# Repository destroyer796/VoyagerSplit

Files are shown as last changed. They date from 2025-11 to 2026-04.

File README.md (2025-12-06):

# VoyagerSplit
A wireless low profile keyboard made for [Hack Club](https://hackclub.com/)'s [Blueprint](https://blueprint.hackclub.com/) program. It uses a staggered columnar layout with 28 keys on each side, with 4 thumb buttons. It uses Kailh Choc switches and Seeed Studio Xiao BLE microcontrollers.

## Why?
I decided to design this keyboard to help improve my typing speed and to give me a mechanical keyboard option for when I'm travelling or away from my PC, as I go into college. I wanted to keep it fairly similar to a conventional keyboard though to prevent too much learning curve.

## Renders
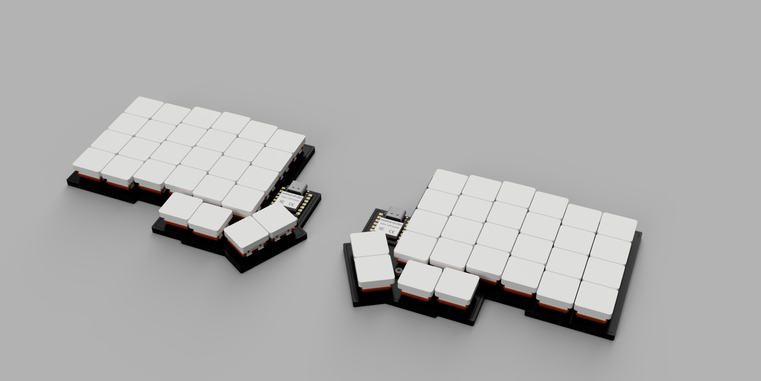
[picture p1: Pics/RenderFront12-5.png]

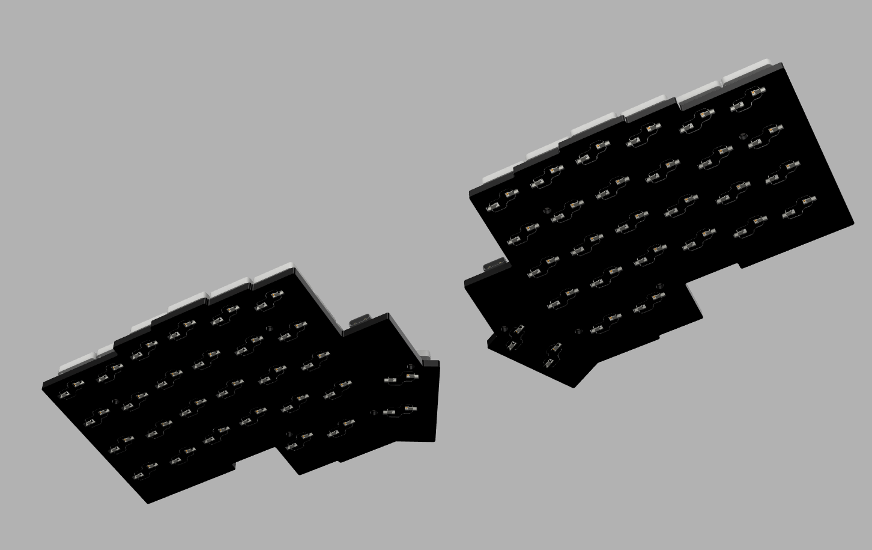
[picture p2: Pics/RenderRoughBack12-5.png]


## PCB
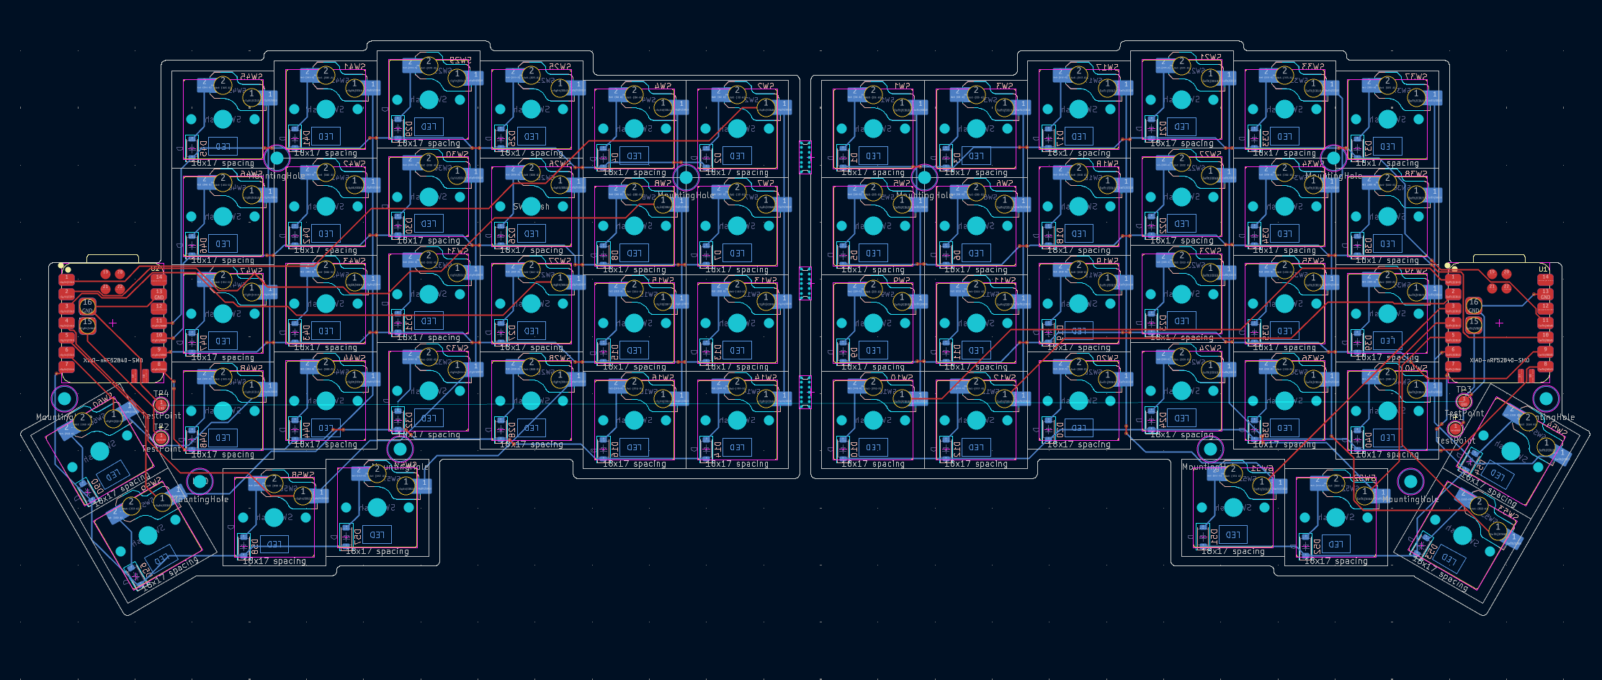
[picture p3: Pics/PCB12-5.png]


## Schematic
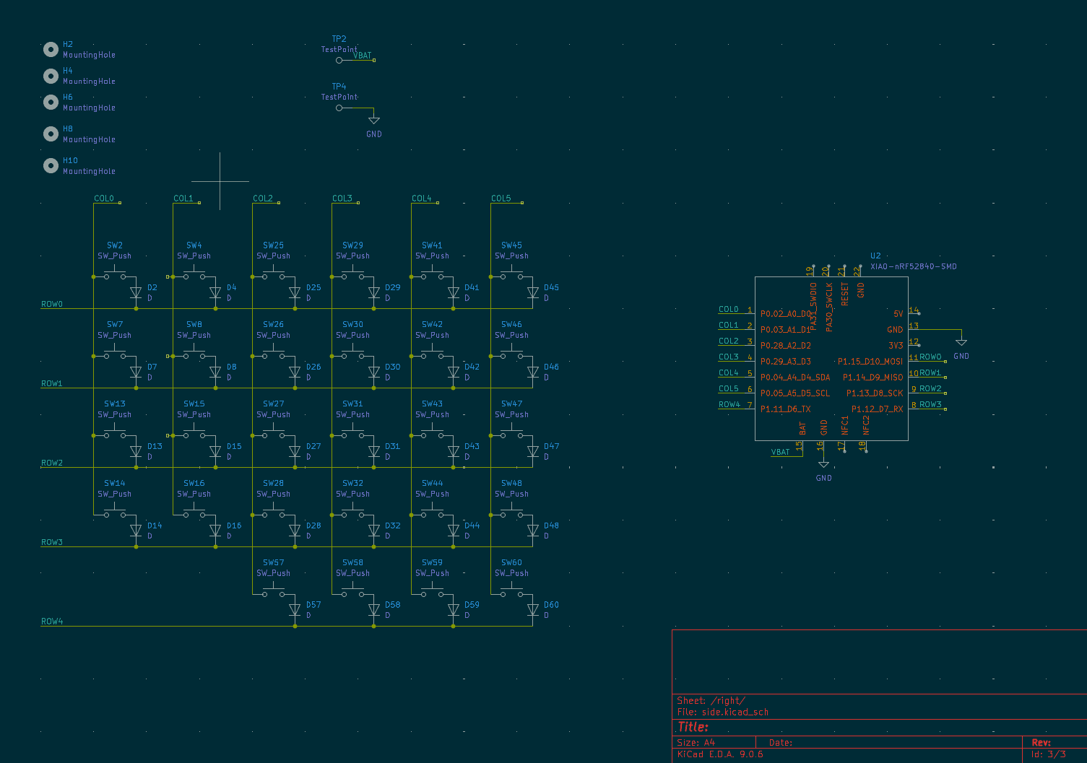
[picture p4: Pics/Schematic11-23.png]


## BOM
|Item |Description |Quantity|Total Price(with shipping)|URL |
|---|---|---|---|---|
|Xiao nRF52840 |Microcontroller|2 |40.06 |https://www.aliexpress.us/item/3256804273304037.html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 |
|1N5819 SOD123 Diodes|Diodes |56 |0.99 |https://www.aliexpress.us/item/3256801808479789.html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 |
|Kailh Choc Reds |Switches |56 |30.83 |https://www.aliexpress.us/item/3256808620484354.html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 |
|Lipo Battery |140 mAh 302025 |2 |5.51 |https://www.aliexpress.us/item/3256808031709894.html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|
|Heatset Inserts |2x2x3 |10 |2.45 |https://www.aliexpress.us/item/3256805885174058.html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 |
|Screws |M2x4 |10 |2.66 |https://www.aliexpress.us/item/3256809725827194.html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 |

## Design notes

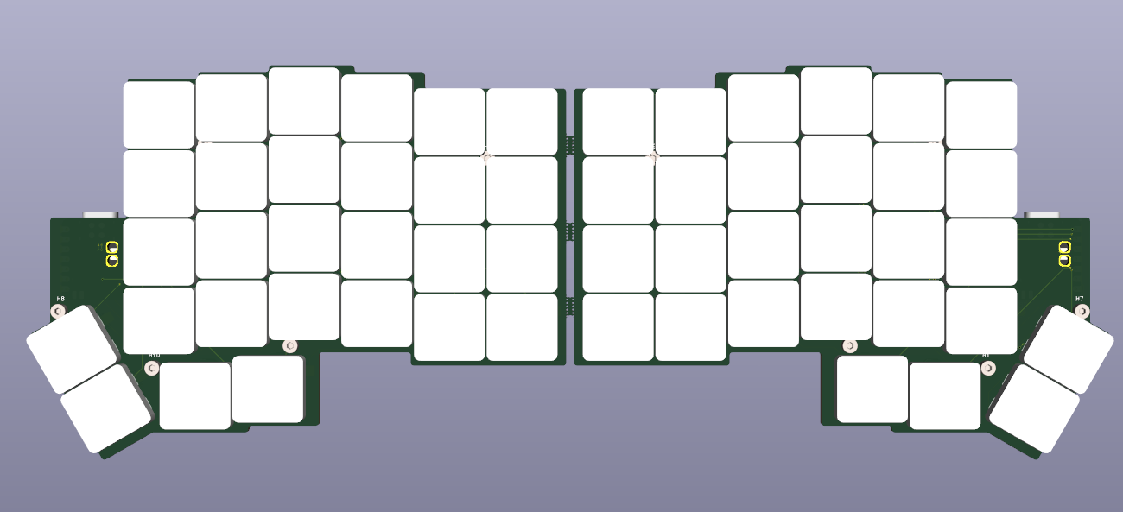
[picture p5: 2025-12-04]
Pics/3DFront12-3.png

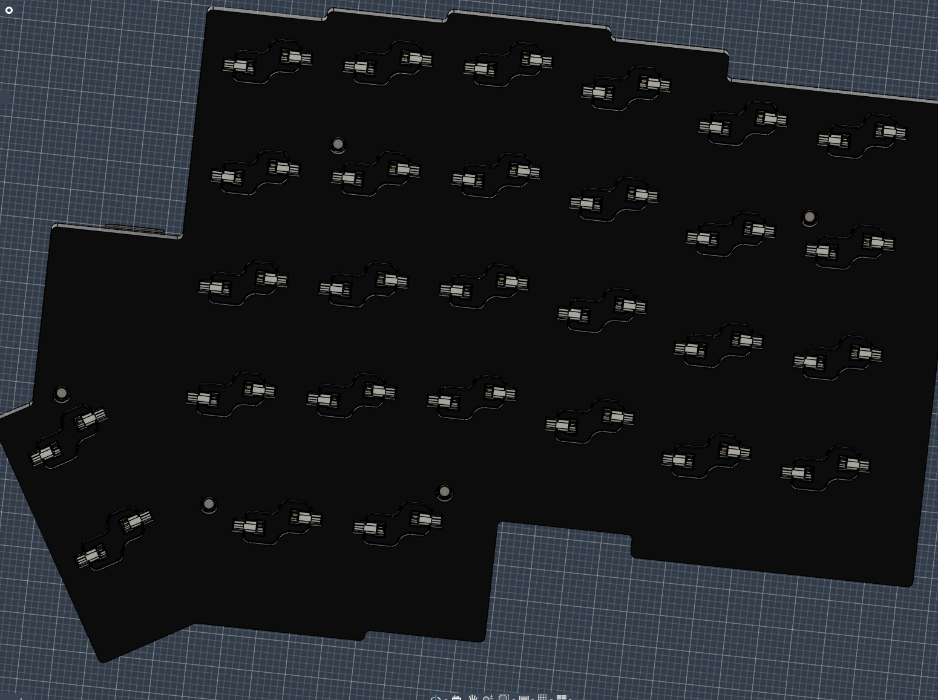
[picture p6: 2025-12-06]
Pics/CADBack12-5.png

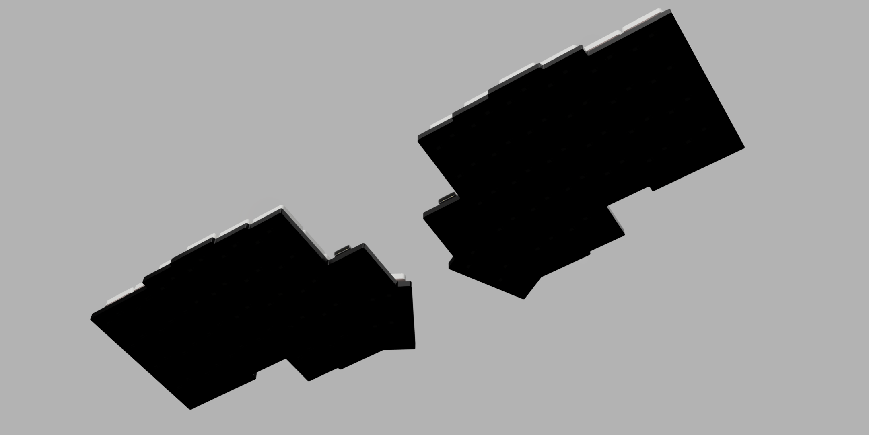
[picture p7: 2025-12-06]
Pics/RenderBack12-5.png

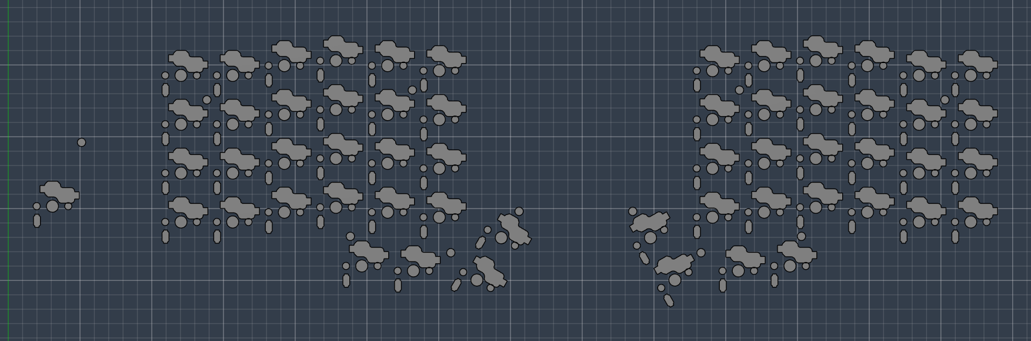
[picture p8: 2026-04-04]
Pics/CADcutouts4-3.png

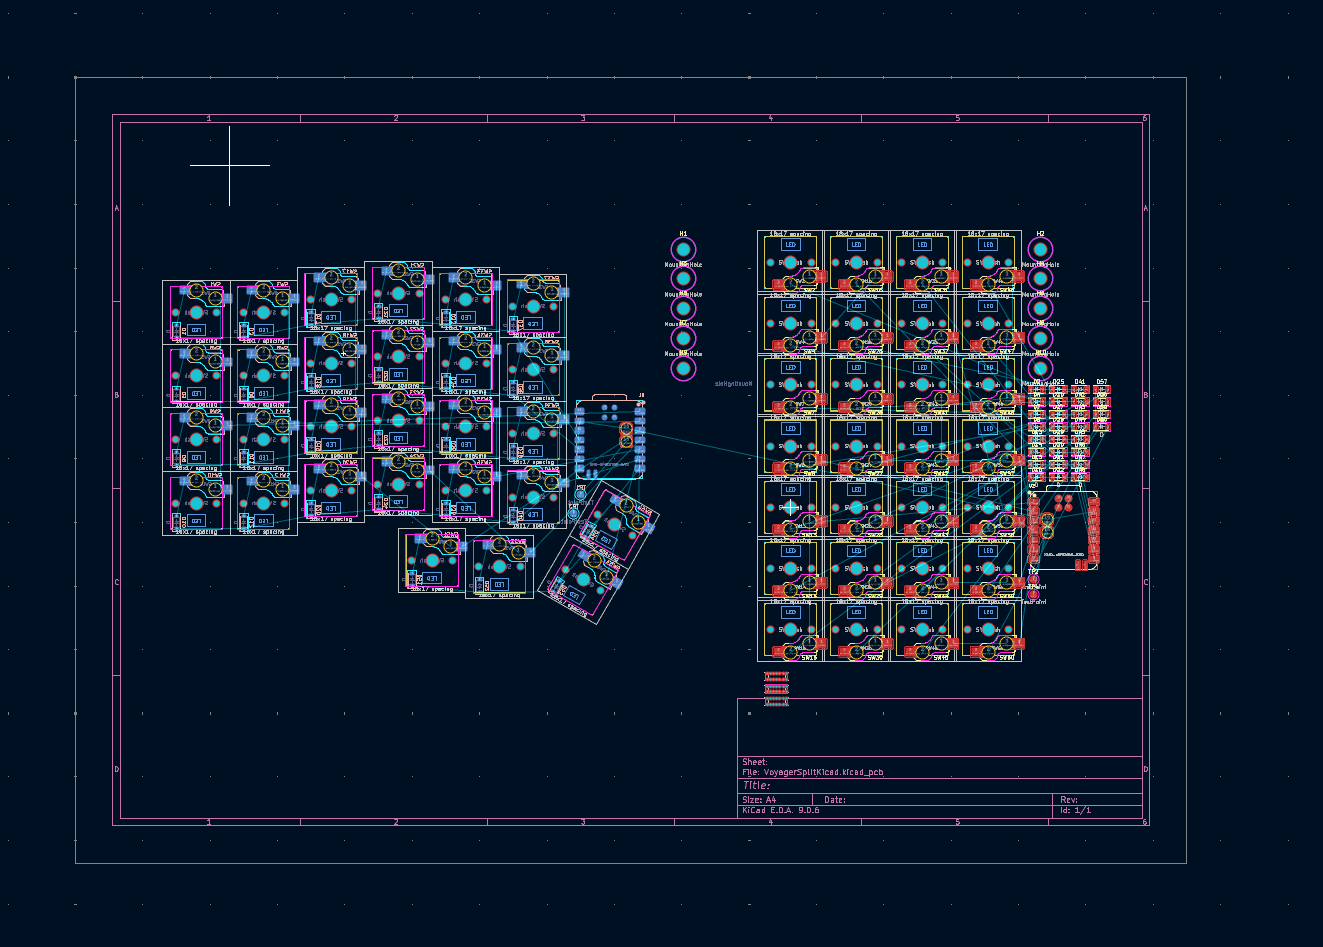
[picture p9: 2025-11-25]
Pics/PCB11-24.png

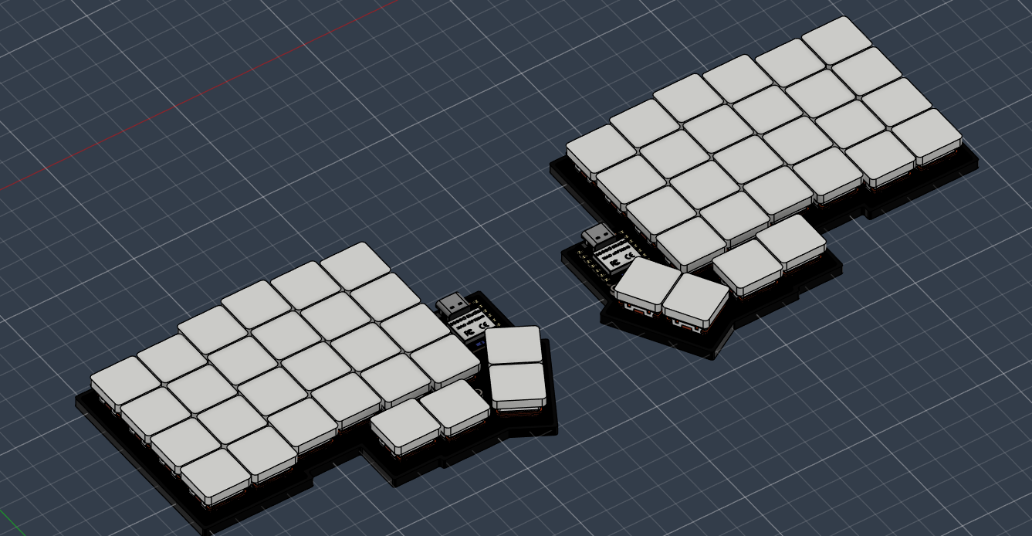
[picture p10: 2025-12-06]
Pics/CADFront12-5.png

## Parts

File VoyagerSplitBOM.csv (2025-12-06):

Item | Description | Quantity | Total Price(with shipping) | URL
Xiao nRF52840 | Microcontroller | 2 | 40.06 | https://www.aliexpress.us/item/3256804273304037.html?curPageLogUid=hr13WqN6qxqv
1N5819 SOD123 Diodes | Diodes | 56 | 0.99 | https://www.aliexpress.us/item/3256801808479789.html?curPageLogUid=OMce55HFjq8i
Kailh Choc Reds | Switches | 56 | 30.83 | https://www.aliexpress.us/item/3256808620484354.html?curPageLogUid=ucF7cwdLXpYV
Lipo Battery | 140 mAh 302025 | 2 | 5.51 | https://www.aliexpress.us/item/3256808031709894.html?curPageLogUid=PHIdYtYGsZTk
Heatset Inserts | 2x2x3 | 10 | 2.45 | https://www.aliexpress.us/item/3256805885174058.html?curPageLogUid=7YsJYdmWdtgS
Screws | M2x4 | 10 | 2.66 | https://www.aliexpress.us/item/3256809725827194.html?curPageLogUid=6hKHBrVGxgKO

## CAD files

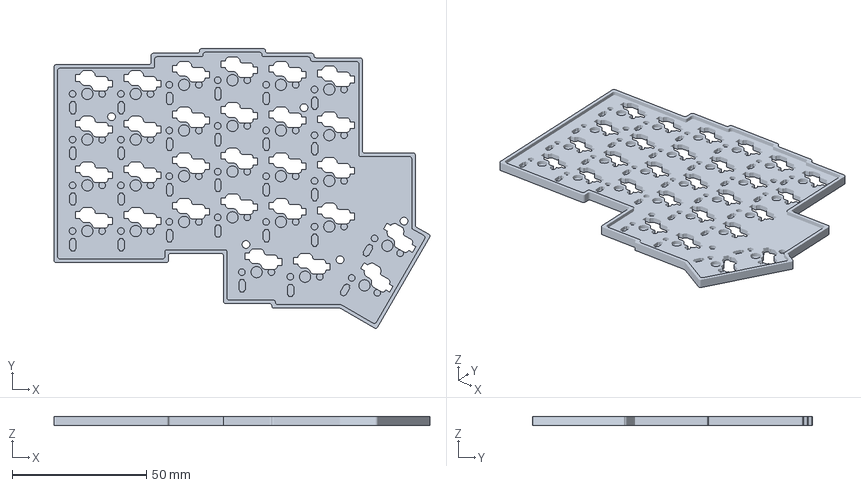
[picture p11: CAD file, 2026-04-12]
CAD/LeftCase2.3mf
139.9 x 104.1 x 3.53 mm

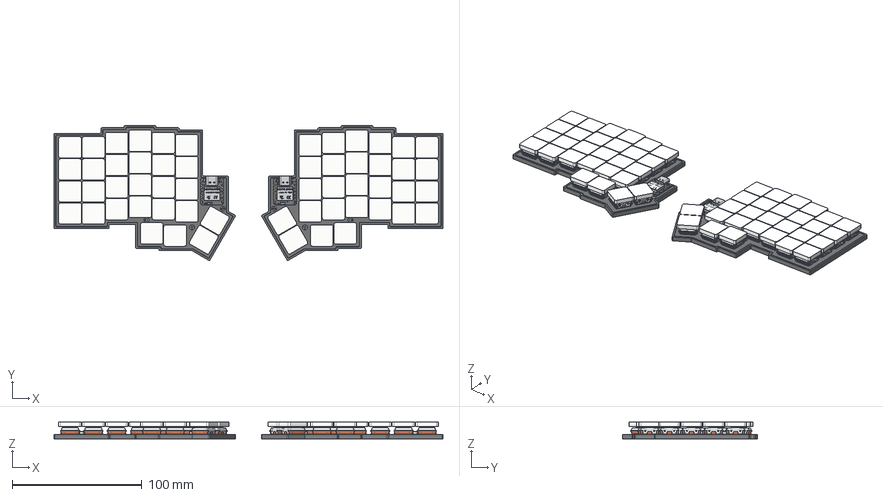
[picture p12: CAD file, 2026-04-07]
CAD/VoyagerSplitSTEP2.step
300.0 x 104.1 x 13.0 mm
VoyagerSplitKicad_PCB
bottom x 56
contact x 56
pin1 x 56
pin2 x 56
stem x 56
top x 56
shrunken_spring x 56
Kailh Choc Plug v1 x 56
D_SOD-123 x 56
pin x 112
socket x 56
Screw_DIN_912_M2x3F_A2 x 10
BOSS-EXTRUDE14_8_ x 2
BOSS-EXTRUDE7_4_ x 2
BOSS-EXTRUDE7_3_ x 2
BOSS-EXTRUDE14_4_ x 2
BOSS-EXTRUDE14_2_ x 2
BOSS-EXTRUDE14_11_ x 2
BOSS-EXTRUDE7_7_ x 2
BOSS-EXTRUDE14_9_ x 2
BOSS-EXTRUDE14_3_ x 2
BOSS-EXTRUDE14_7_ x 2
MIRROR2 x 2
BOSS-EXTRUDE14_5_ x 2
BOSS-EXTRUDE14_12_ x 2
BOSS-EXTRUDE7_8_ x 2
BOSS-EXTRUDE7_1_ x 2
BOSS-EXTRUDE14_10_ x 2
BOSS-EXTRUDE7_9_ x 2
BOSS-EXTRUDE14_6_ x 2
BOSS-EXTRUDE14_1_ x 2
BOSS-EXTRUDE7_6_ x 2
BOSS-EXTRUDE7_2_ x 2
CUT-EXTRUDE5 x 2
BOSS-EXTRUDE7_5_ x 2
Shield x 2
Pins x 2
CAP x 4
ANT1 x 2
Silkscreen x 2
CAP 3 x 2
LED x 2
USR x 2

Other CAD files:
CAD/RightCase2.3mf
CAD/VoyagerSplitFusion2.f3z

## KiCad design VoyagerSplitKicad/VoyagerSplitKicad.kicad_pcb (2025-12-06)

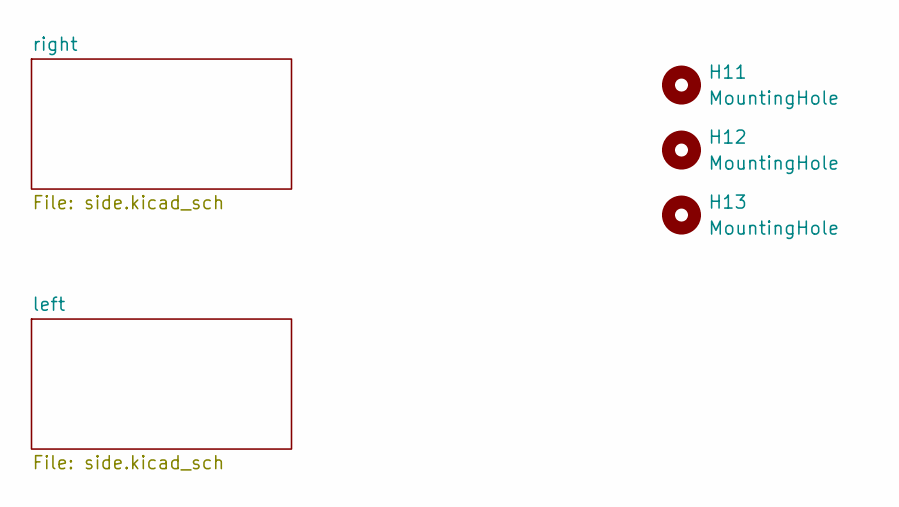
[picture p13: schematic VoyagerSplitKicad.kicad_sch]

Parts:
H11, H12, H13: MountingHole; MouseBite-Slot_2.0x4.5mm_outset_D0.5mm_P0.85mm_7h

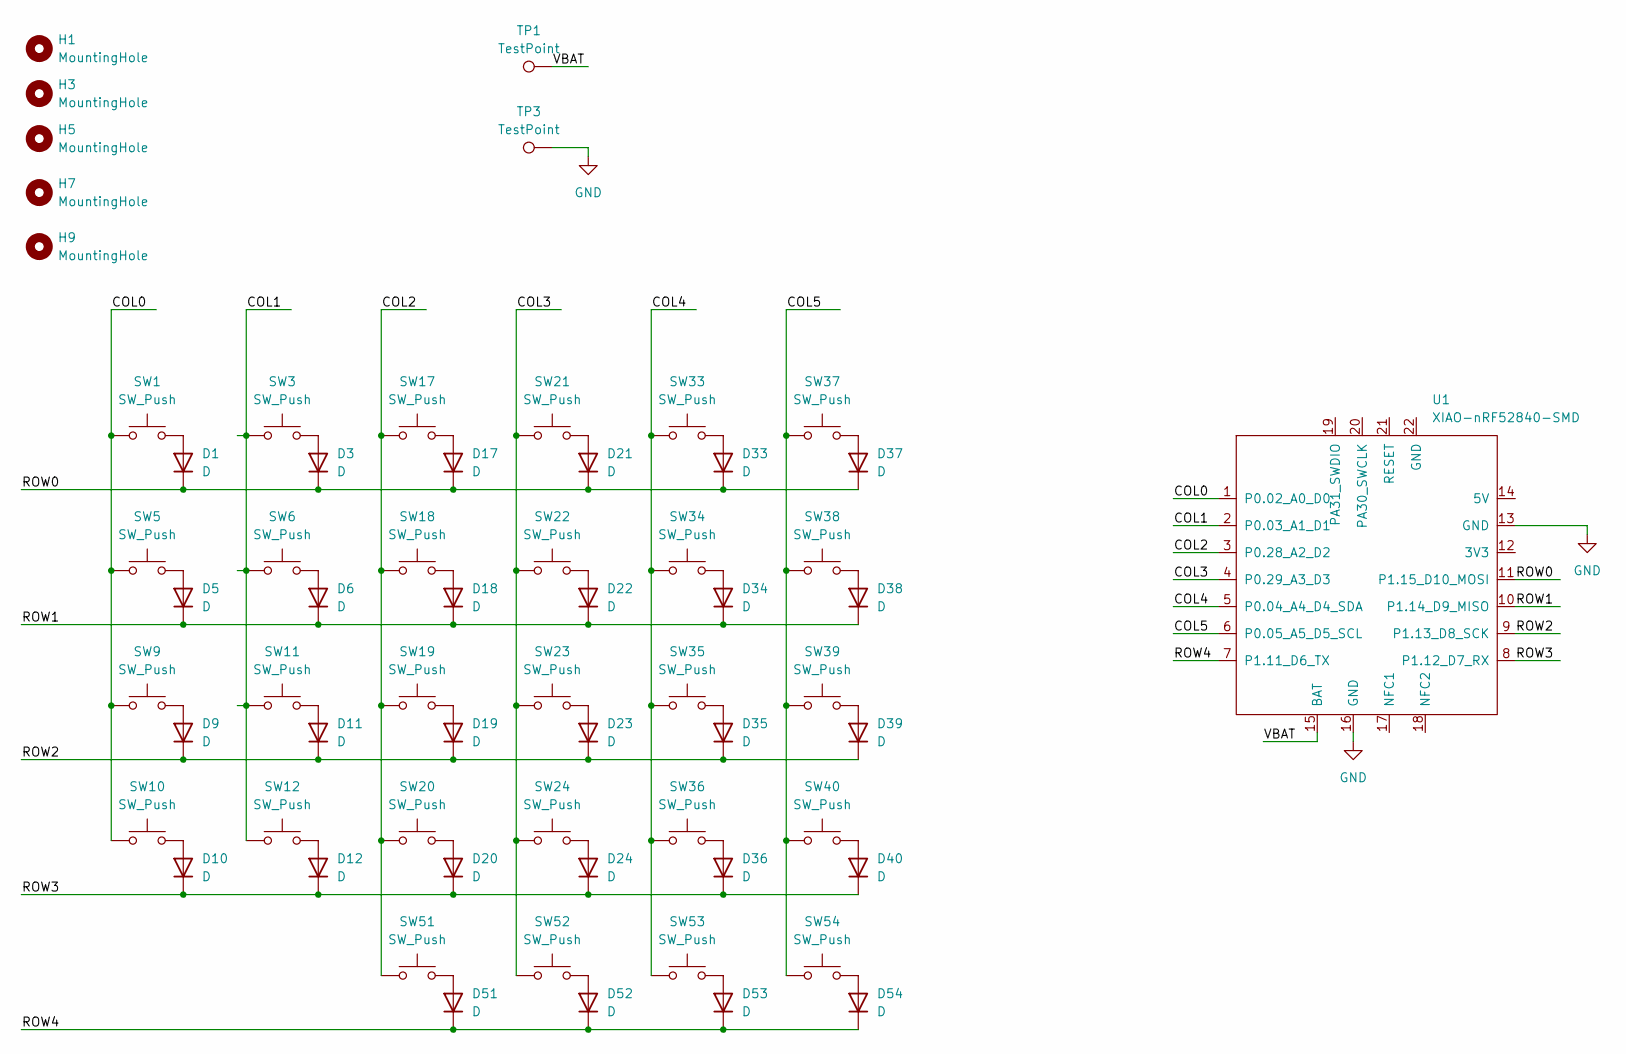
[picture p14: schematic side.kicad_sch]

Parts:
D1, D3, D5, D6, D9, D10, D11, D12, D17, D18, D19, D20, D21, D22, D23, D24, D33, D34, D35, D36, D37, D38, D39, D40, D51, D52, D53, D54: D; D_SOD-123
H1, H3, H5, H7, H9: MountingHole; MountingHole_2.2mm_M2
SW1, SW3, SW5, SW6, SW9, SW10, SW11, SW12, SW17, SW18, SW19, SW20, SW21, SW22, SW23, SW24, SW33, SW34, SW35, SW36, SW37, SW38, SW39, SW40, SW51, SW52, SW53, SW54: SW_Push; SW_choc_v1_HS_CPG135001S30_1u
TP1, TP3: TestPoint; TestPoint_Pad_D2.0mm
U1: XIAO-nRF52840-SMD; modified-XIAO-nRF52840-SMD

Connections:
/left/COL0: SW1.1, SW5.1, SW9.1, SW10.1, U1.1 (P0.02_A0_D0)
/left/COL1: SW3.1, SW6.1, SW11.1, SW12.1, U1.2 (P0.03_A1_D1)
/left/COL2: SW17.1, SW18.1, SW19.1, SW20.1, SW51.1, U1.3 (P0.28_A2_D2)
/left/COL3: SW21.1, SW22.1, SW23.1, SW24.1, SW52.1, U1.4 (P0.29_A3_D3)
/left/COL4: SW33.1, SW34.1, SW35.1, SW36.1, SW53.1, U1.5 (P0.04_A4_D4_SDA)
/left/COL5: SW37.1, SW38.1, SW39.1, SW40.1, SW54.1, U1.6 (P0.05_A5_D5_SCL)
/left/ROW0: D1.1 (K), D3.1 (K), D17.1 (K), D21.1 (K), D33.1 (K), D37.1 (K), U1.11 (P1.15_D10_MOSI)
/left/ROW1: D5.1 (K), D6.1 (K), D18.1 (K), D22.1 (K), D34.1 (K), D38.1 (K), U1.10 (P1.14_D9_MISO)
/left/ROW2: D9.1 (K), D11.1 (K), D19.1 (K), D23.1 (K), D35.1 (K), D39.1 (K), U1.9 (P1.13_D8_SCK)
/left/ROW3: D10.1 (K), D12.1 (K), D20.1 (K), D24.1 (K), D36.1 (K), D40.1 (K), U1.8 (P1.12_D7_RX)
/left/ROW4: D51.1 (K), D52.1 (K), D53.1 (K), D54.1 (K), U1.7 (P1.11_D6_TX)
/left/VBAT: U1.15 (BAT); also elsewhere on the board
GND: TP3.1, U1.13 (GND), U1.16 (GND); also elsewhere on the board
unnamed: D1.2 (A), SW1.2
unnamed: D3.2 (A), SW3.2
unnamed: D5.2 (A), SW5.2
unnamed: D6.2 (A), SW6.2
unnamed: D9.2 (A), SW9.2
unnamed: D10.2 (A), SW10.2
unnamed: D11.2 (A), SW11.2
unnamed: D12.2 (A), SW12.2
unnamed: D17.2 (A), SW17.2
unnamed: D18.2 (A), SW18.2
unnamed: D19.2 (A), SW19.2
unnamed: D20.2 (A), SW20.2
unnamed: D21.2 (A), SW21.2
unnamed: D22.2 (A), SW22.2
unnamed: D23.2 (A), SW23.2
unnamed: D24.2 (A), SW24.2
unnamed: D33.2 (A), SW33.2
unnamed: D34.2 (A), SW34.2
unnamed: D35.2 (A), SW35.2
unnamed: D36.2 (A), SW36.2
unnamed: D37.2 (A), SW37.2
unnamed: D38.2 (A), SW38.2
unnamed: D39.2 (A), SW39.2
unnamed: D40.2 (A), SW40.2
unnamed: D51.2 (A), SW51.2
unnamed: D52.2 (A), SW52.2
unnamed: D53.2 (A), SW53.2
unnamed: D54.2 (A), SW54.2

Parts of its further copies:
D2, D4, D7, D8, D13, D14, D15, D16, D25, D26, D27, D28, D29, D30, D31, D32, D41, D42, D43, D44, D45, D46, D47, D48, D57, D58, D59, D60: D; D_SOD-123
H2, H4, H6, H8, H10: MountingHole; MountingHole_2.2mm_M2
SW2, SW4, SW7, SW8, SW13, SW14, SW15, SW16, SW25, SW26, SW27, SW28, SW29, SW30, SW31, SW32, SW41, SW42, SW43, SW44, SW45, SW46, SW47, SW48, SW57, SW58, SW59, SW60: SW_Push; SW_choc_v1_HS_CPG135001S30_1u
U2: XIAO-nRF52840-SMD; modified-XIAO-nRF52840-SMD

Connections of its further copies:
/right/COL0: SW2.1, SW7.1, SW13.1, SW14.1, U2.1 (P0.02_A0_D0)
/right/COL1: SW4.1, SW8.1, SW15.1, SW16.1, U2.2 (P0.03_A1_D1)
/right/COL2: SW25.1, SW26.1, SW27.1, SW28.1, SW57.1, U2.3 (P0.28_A2_D2)
/right/COL3: SW29.1, SW30.1, SW31.1, SW32.1, SW58.1, U2.4 (P0.29_A3_D3)
/right/COL4: SW41.1, SW42.1, SW43.1, SW44.1, SW59.1, U2.5 (P0.04_A4_D4_SDA)
/right/COL5: SW45.1, SW46.1, SW47.1, SW48.1, SW60.1, U2.6 (P0.05_A5_D5_SCL)
/right/ROW0: D2.1 (K), D4.1 (K), D25.1 (K), D29.1 (K), D41.1 (K), D45.1 (K), U2.11 (P1.15_D10_MOSI)
/right/ROW1: D7.1 (K), D8.1 (K), D26.1 (K), D30.1 (K), D42.1 (K), D46.1 (K), U2.10 (P1.14_D9_MISO)
/right/ROW2: D13.1 (K), D15.1 (K), D27.1 (K), D31.1 (K), D43.1 (K), D47.1 (K), U2.9 (P1.13_D8_SCK)
/right/ROW3: D14.1 (K), D16.1 (K), D28.1 (K), D32.1 (K), D44.1 (K), D48.1 (K), U2.8 (P1.12_D7_RX)
/right/ROW4: D57.1 (K), D58.1 (K), D59.1 (K), D60.1 (K), U2.7 (P1.11_D6_TX)
/right/VBAT: U2.15 (BAT); also elsewhere on the board
GND: U2.13 (GND), U2.16 (GND); also elsewhere on the board
unnamed: D2.2 (A), SW2.2
unnamed: D4.2 (A), SW4.2
unnamed: D7.2 (A), SW7.2
unnamed: D8.2 (A), SW8.2
unnamed: D13.2 (A), SW13.2
unnamed: D14.2 (A), SW14.2
unnamed: D15.2 (A), SW15.2
unnamed: D16.2 (A), SW16.2
unnamed: D25.2 (A), SW25.2
unnamed: D26.2 (A), SW26.2
unnamed: D27.2 (A), SW27.2
unnamed: D28.2 (A), SW28.2
unnamed: D29.2 (A), SW29.2
unnamed: D30.2 (A), SW30.2
unnamed: D31.2 (A), SW31.2
unnamed: D32.2 (A), SW32.2
unnamed: D41.2 (A), SW41.2
unnamed: D42.2 (A), SW42.2
unnamed: D43.2 (A), SW43.2
unnamed: D44.2 (A), SW44.2
unnamed: D45.2 (A), SW45.2
unnamed: D46.2 (A), SW46.2
unnamed: D47.2 (A), SW47.2
unnamed: D48.2 (A), SW48.2
unnamed: D57.2 (A), SW57.2
unnamed: D58.2 (A), SW58.2
unnamed: D59.2 (A), SW59.2
unnamed: D60.2 (A), SW60.2

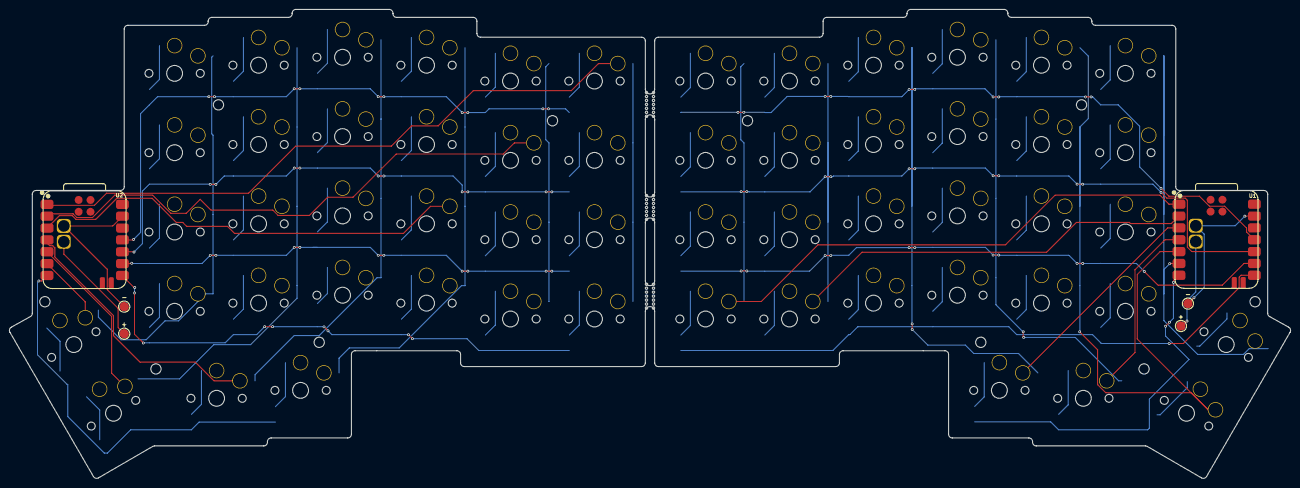
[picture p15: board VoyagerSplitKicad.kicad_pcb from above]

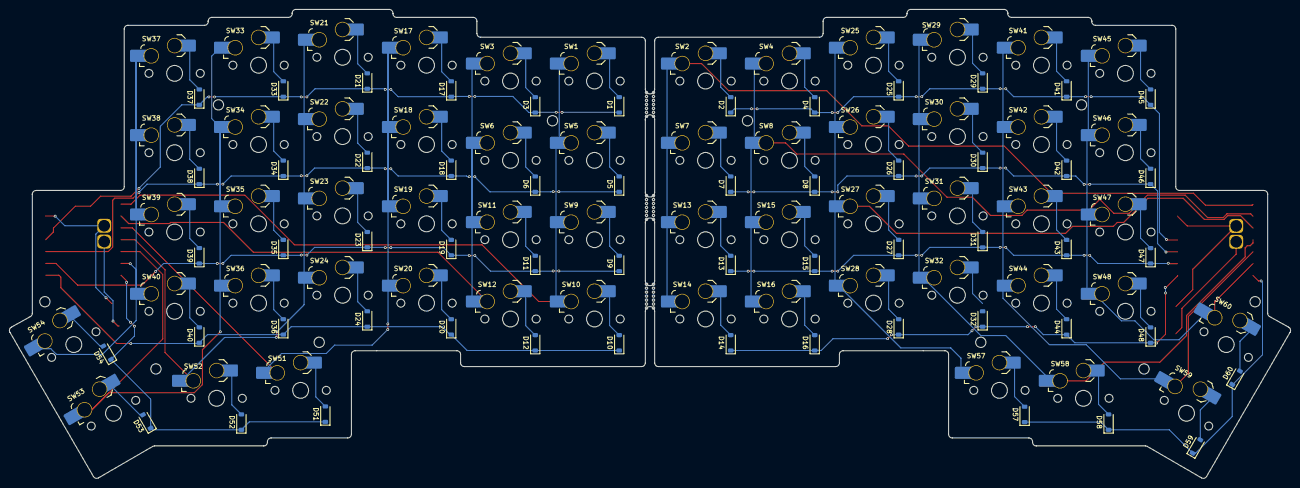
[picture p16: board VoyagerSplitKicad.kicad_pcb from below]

Board: 2 copper layers, 274.6 x 100.5 mm, 131 parts (112 on the bottom side), 81 nets.

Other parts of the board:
+: TestPoint; TestPoint_Pad_D2.0mm
+#2: TestPoint; TestPoint_Pad_D2.0mm
-: TestPoint; TestPoint_Pad_D2.0mm
-#2: TestPoint; TestPoint_Pad_D2.0mm

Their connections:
/left/VBAT: +#2.1; also elsewhere on the board
/right/VBAT: +.1; also elsewhere on the board
GND: -.1, -#2.1; also elsewhere on the board

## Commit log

2025-11-24 kicad schematic
    [VoyagerSplitKicad.kicad_pcb, VoyagerSplitKicad.kicad_sch, side.kicad_sch]
2025-11-25 layed out one half of pcb
    [VoyagerSplitKicad.kicad_pcb, VoyagerSplitKicad.kicad_sch, side.kicad_sch]
2025-11-27 laying out 2nd half of PCB and getting edge cut
    [VoyagerSplitKicad.kicad_pcb, side.kicad_sch]
2025-12-04 added 3d
    [VoyagerSplitKicad-B_Cu.gbr, VoyagerSplitKicad-B_Mask.gbr, VoyagerSplitKicad-B_Paste.gbr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]
2025-12-05 flipped xiao
    [VoyagerSplitKicad-B_Cu.gbr, VoyagerSplitKicad-B_Mask.gbr, VoyagerSplitKicad-B_Paste.gbr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]
2026-04-01 soldered half!
2026-04-07 updated cad
    [LeftCase.3mf, LeftCase2.3mf, RightCase.3mf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]
